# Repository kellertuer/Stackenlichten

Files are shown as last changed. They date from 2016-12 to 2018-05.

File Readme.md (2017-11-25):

# Stackenlichten
<div align="right">by <a href="https://twitter.com/kellertuer">@kellertuer</a>, <a href="https://twitter.com/k4sp4r">@k4spar</a>.</div>
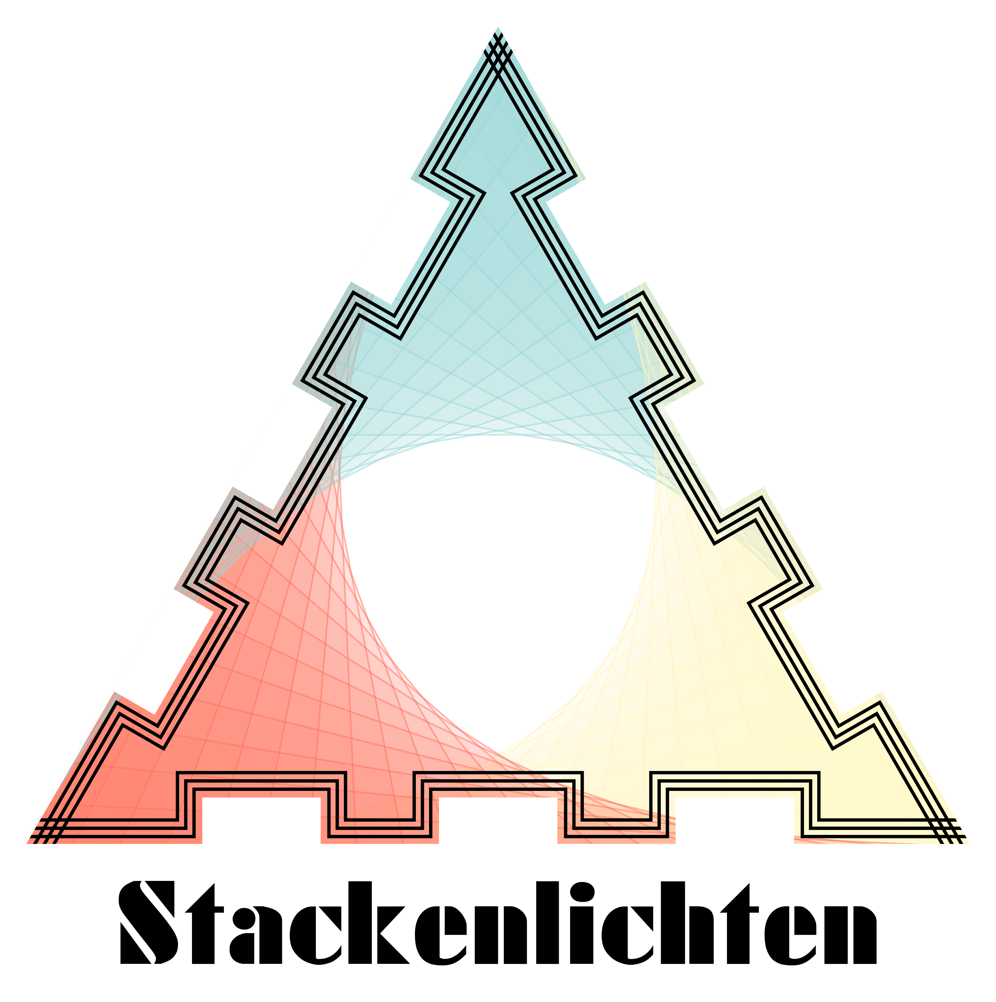
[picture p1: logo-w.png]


## Motivation
The idea of this project is to provide a blueprint for single pixels, that
can be connected via magnets. The data and power supply works via connectors.
The pixels themselves are equilateral triangles, that can easier be used to
stack different forms of Lichten.

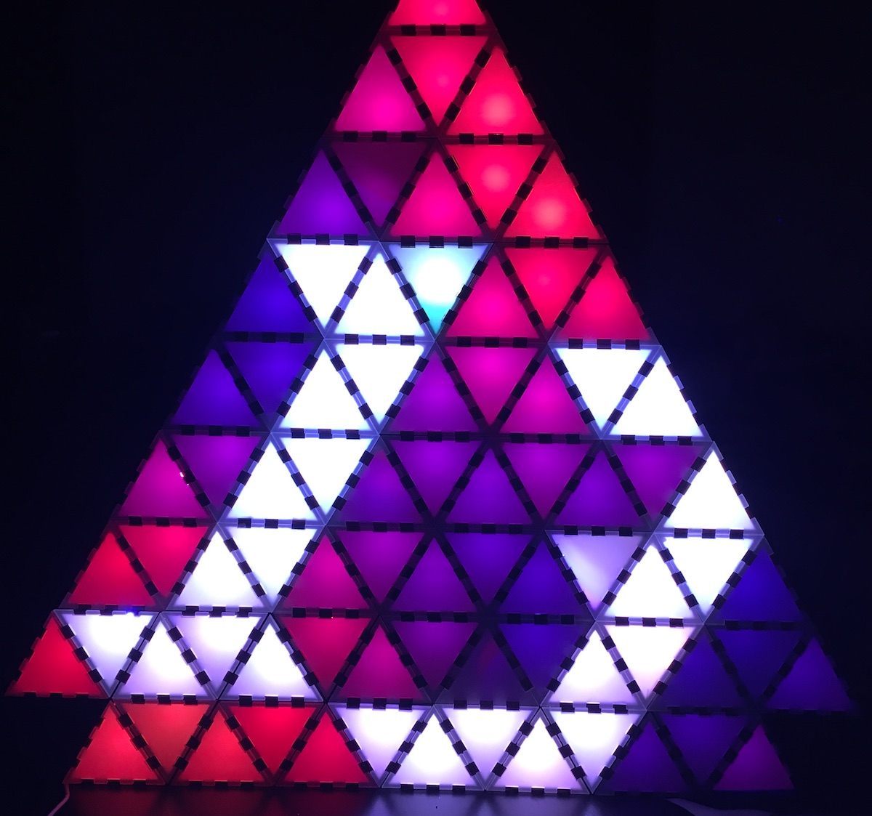
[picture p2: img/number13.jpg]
status


## Code
Based on the fadecandy chip and its accompanying python code, The code for Stackenlichten encapsulates the interface to the pixel and provides an easy way to implement image and pixel algorithms on graphs.

## A Talk with a Demo
There was a Talk at the [MetaNook 2017](https://metanook.de) by [@kellertuer](https://twitter.com/kellertuer) (in german though). The slides can be viewed [here](http://ronnybergmann.net/vortraege/2017-11-Stackenlichten-MetaNook.pdf) and a recording is available on the [Youtube channel of the MetaNook](https://www.youtube.com/watch?v=ggBUx7R-tWU) (demo starts at about 44 minutes).

## Build your own
In order to build your own Trixels, see [Manual.md](manual/manual.md).

## KuDos
* [Blinkenlichten](http://blinkenlights.net)
* [Stackenblochen](https://www.youtube.com/watch?v=QEN5-_93gQg)
* [inKL](http://chaos-inkl.de) for all 3D printing help
* [@k4spar](http://twitter.com/k4spar) for a lot of laz0r wood and discussions in the begginnig of the trixel idea at the [33c3](https://events.ccc.de/congress/2016/wiki/Main_Page).
* Haruto end eBrnd as well as [FabLab KA](https://fablab-karlsruhe.de) for even more laz0r

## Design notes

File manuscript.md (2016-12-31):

# Stackenlichten
<div align="right"> by [@kellertuer](https://twitter,com/kellertuer), [@k4sp4r](https://twitter.com/k4sp4r)</div>
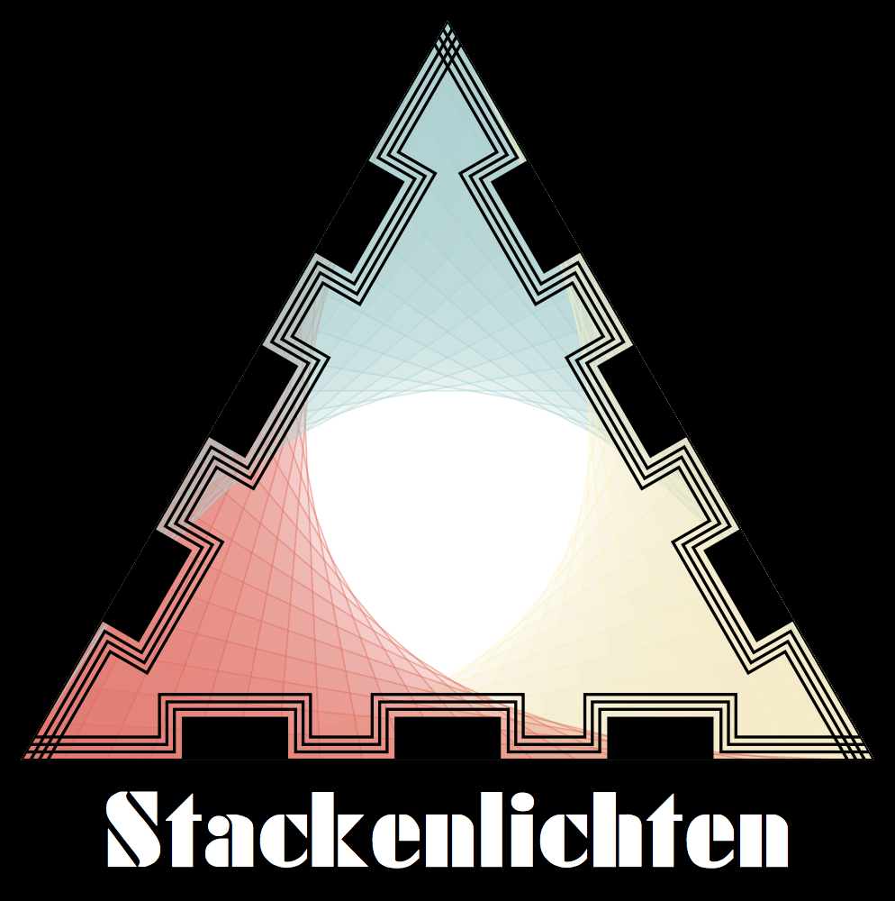
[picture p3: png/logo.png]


## Motivation
The idea of this project is to provide a blueprint for single pixels, that
can be connected via magnets. The data and power supply works via connectors.
The pixels themselves are equilateral triangles, that can easire be used to
stack different forms of Lichten.

## Material
For bulding one of the pixels the following is required
* 6 [Neodyn magnets](https://www.magnetversand.de/en/neodymium-magnet-cube-4x4x4-mm/a-173/) of size `4x4x4 mm` (0,16 €)
* 1 [connector](https://www.reichelt.de/Molex-Vielfachsteckverbinder/MOLEX-22035035/3/index.html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) (0,14 €)
* 1 [jack](https://www.reichelt.de/Molex-Vielfachsteckverbinder/MOLEX-50375033/3/index.html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) (0,10 €)
* 1 [NeoPixel](https://www.adafruit.com/products/1559) (1,75 €) or any other WS2812 LED having the classical 4 ports +,-,in,out
* 4mm thick wood
* a laser cutter

## Sketches
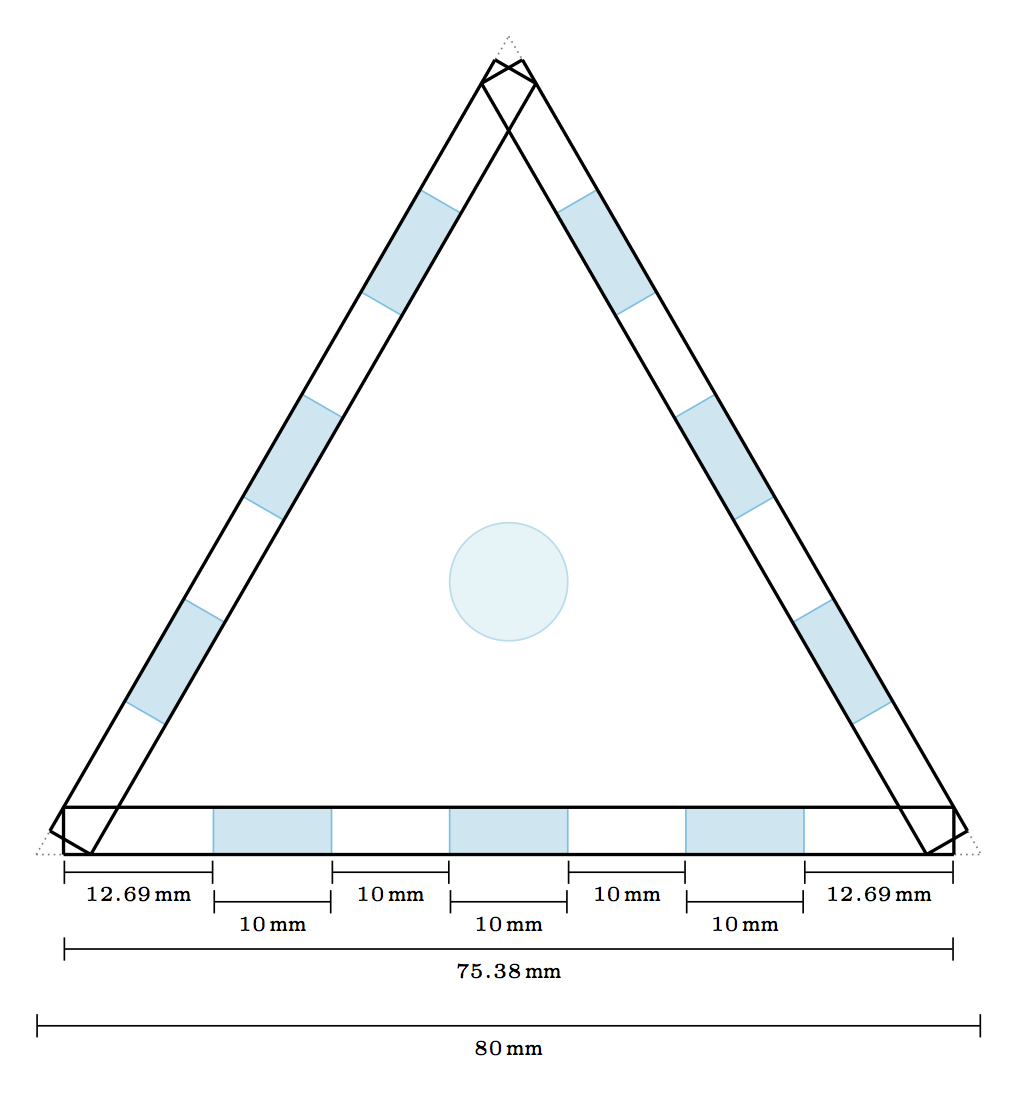
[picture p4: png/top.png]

Seen from the top, the pixel consists of 3 equal sides. with finger joints of
1cm indicated in cyan (the fingers). The three sides are shortened, such that
the edges don't overlap the triangular shape.
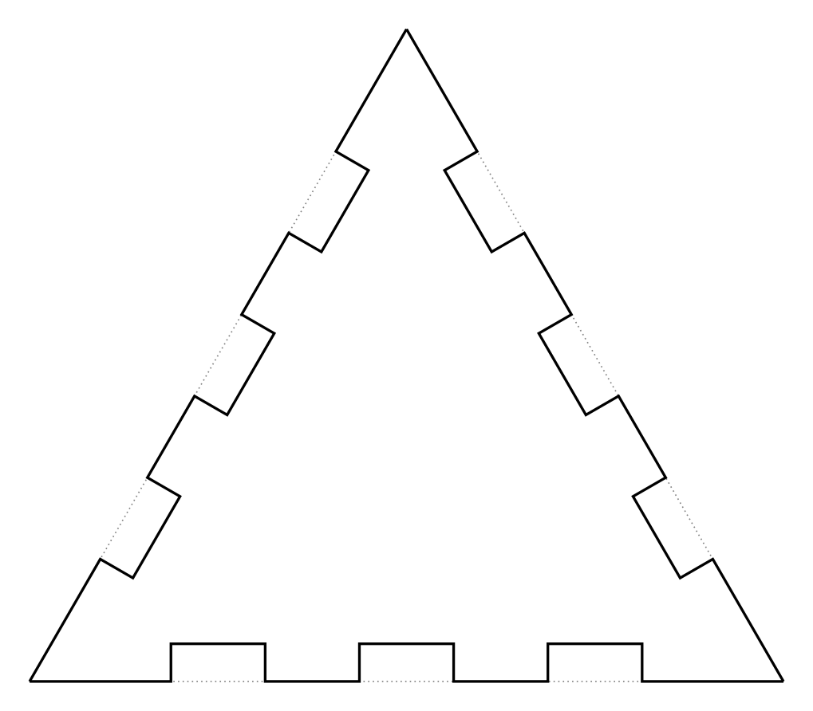
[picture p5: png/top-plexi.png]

The top plate made of plexi glas obtains a shape, that looks quite fance but is
basically just the triangular shape with the fingers of `0.4x1 cm` cut out.
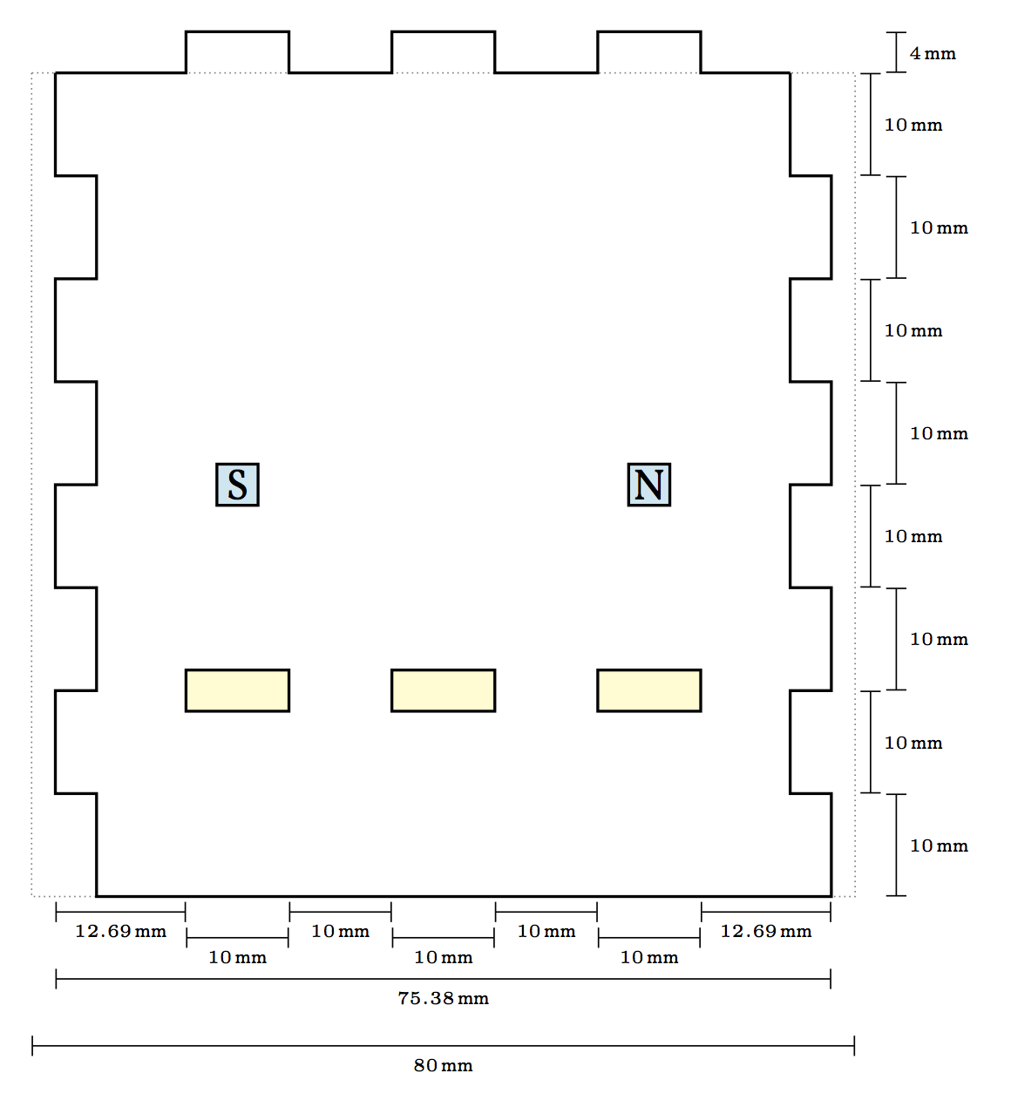
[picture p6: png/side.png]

Each side plate is made with equal fingers for the sides, but for each pixel
two sides sould consists of the same pole pointing outward ([S]outh in the sketch)
and one having the other. This yields South dominated or North dominated pixels,
which should be produced in equal amounts.
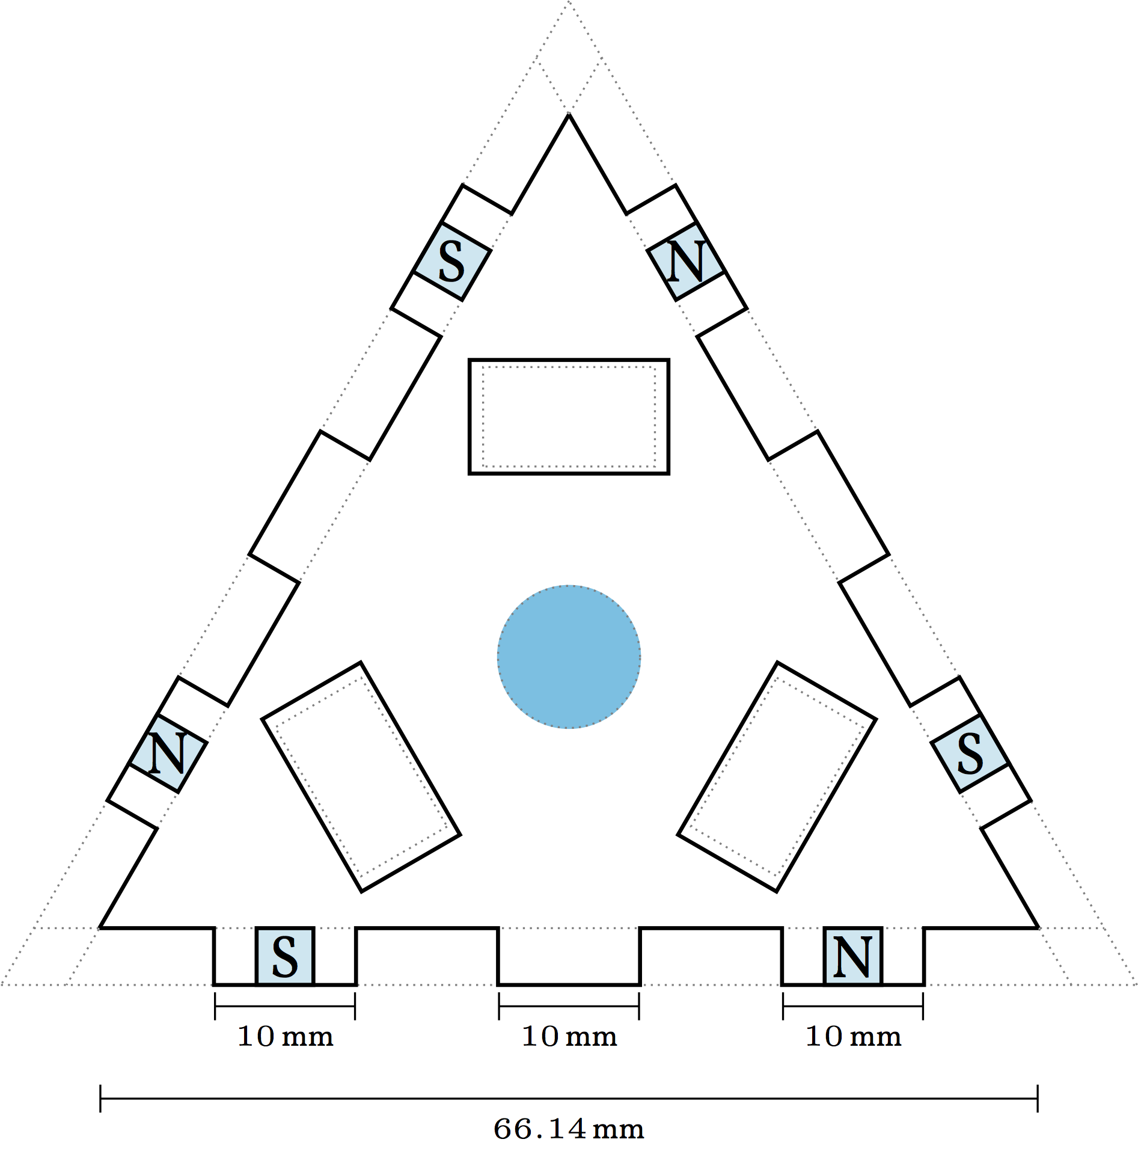
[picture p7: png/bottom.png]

The bottom plate is placed 1cm inwards of the sides with 2 bolts for each side.
The magnets should join into the sides by 3/4th (`3 mm`) the top one should be
glued, the bottom one should be held by the bottom plate.

## KuDos
* [Blinkenlichten](http://blinkenlights.net)
* [Stackenblochen](https://www.youtube.com/watch?v=QEN5-_93gQg)

## TODO
The sketches have to be transformed into laser cutting plans and a layout of
the jacks has to be made for a usual bottom plate (placement of the connector,
  length of the cable to the jack (10cm?).

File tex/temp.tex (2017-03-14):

\documentclass[border=0mm]{standalone}
\usepackage[no-math]{fontspec}
\usepackage{xunicode,xltxtra}
\usepackage{tikz,pgfplots}
\usetikzlibrary{calc,backgrounds,pgfplots.colormaps}
% Font
\defaultfontfeatures{Mapping=tex-text}
\setromanfont[Ligatures={Common},ItalicFont={Vollkorn-Italic},BoldFont={Vollkorn-Bold}, BoldItalicFont={Vollkorn-BoldItalic}]{Vollkorn}
%
% Styles
\tikzset{base/.style={gray,densely dotted,thin}}
\tikzset{main/.style={thick}}
\tikzset{minor/.style={dashed}}
\tikzset{holes/.style={thick,fill=yellow!20}}
\tikzset{magnets/.style={thick,fill=cyan!20}}
\tikzset{measure/.style={thin,|-|}}
\tikzset{emph/.style={fill=cyan!10!white,cyan!60!white}}
\tikzset{neo/.style={fill=cyan!20!white,cyan!60!white}}
\tikzset{every node/.style={font=\tiny}}
%
% Display lengths
\newif\ifshowLengths
\showLengthstrue
%\showLengthsfalse
%
%
% Sizes
%
% if unsure leave them as they're because that's the production standard for now
\newcommand\wTh{0.4} %woodThickness in cm, short W in comments
\newcommand\mTh{0.4} %MagnetThickness in cm, short M in comments
\newcommand\pTh{0.2} %plexi frontplare Thickness
\newcommand\sL{8.0} %length of a side of the Triangle
\newcommand\h{8.0} % height of the side
\begin{document}
    \begin{tikzpicture}
    \ifshowLengths
      \draw[base] (-\sL/2,0) -- (\sL/2,0);
      \draw[base] ({- (\sL/2- \wTh*cot(60)) },\wTh)--({\sL/2- \wTh*cot(60)},\wTh);
    \fi
    \draw [magnets] (-\sL/4-\mTh/2,\mTh) rectangle (-\sL/4+\mTh/2,0);
    \draw [magnets] (\sL/4-\mTh/2,\mTh) rectangle (\sL/4+\mTh/2,0);
    \ifshowLengths
      \node (A2) at (-\sL/4,\mTh/2) {\large S};
      \node (A1) at (\sL/4,\mTh/2) {\large N};
    \fi
    \draw[main] ({- (\sL/2-\wTh*cot(60) - \wTh/sin(60) )}, \wTh)
      -- (-5/16*\sL,\wTh) -- (-5/16*\sL,0) -- (-3/16*\sL,0) -- (-3/16*\sL,\wTh)
      -- (-1/16*\sL,\wTh) -- (-1/16*\sL,0) -- (1/16*\sL,0) -- (1/16*\sL,\wTh)
      -- (3/16*\sL,\wTh) -- (3/16*\sL,0) -- (5/16*\sL,0) -- (5/16*\sL,\wTh) 
      -- ({\sL/2- \wTh*cot(60) - \wTh/sin(60)},\wTh);
    % hole for plugs
    \draw[main,rounded corners=3mm]
      (-.75,{4/3*sqrt(3)+.8-.6}) rectangle (.75,{4/3*sqrt(3)+.8+.6});
    \draw[main, rounded corners=3mm]
      (-.75,{4/3*sqrt(3)-.75-.5}) rectangle (.75,{4/3*sqrt(3)-.75+.5});
    \begin{scope}[shift={(-\sL/4,{2*sqrt(3)})},rotate=-120]
    \ifshowLengths
      \draw[base] (-\sL/2,0) -- (\sL/2,0);
      \draw[base] ({- (\sL/2- \wTh*cot(60)) },\wTh)--({\sL/2- \wTh*cot(60)},\wTh);
    \fi
    \draw [magnets] (-\sL/4-\mTh/2,\mTh) rectangle (-\sL/4+\mTh/2,0);
    \draw [magnets] (\sL/4-\mTh/2,\mTh) rectangle (\sL/4+\mTh/2,0);
    \ifshowLengths
      \node (A2) at (-\sL/4,\mTh/2) {\large S};
      \node (A1) at (\sL/4,\mTh/2) {\large N};
    \fi
    \draw[main] ({- (\sL/2-\wTh*cot(60) - \wTh/sin(60) )}, \wTh)
      -- (-5/16*\sL,\wTh) -- (-5/16*\sL,0) -- (-3/16*\sL,0) -- (-3/16*\sL,\wTh)
      -- (-1/16*\sL,\wTh) -- (-1/16*\sL,0) -- (1/16*\sL,0) -- (1/16*\sL,\wTh)
      -- (3/16*\sL,\wTh) -- (3/16*\sL,0) -- (5/16*\sL,0) -- (5/16*\sL,\wTh) 
      -- ({\sL/2- \wTh*cot(60) - \wTh/sin(60)},\wTh);
    \end{scope}
    \begin{scope}[shift={(\sL/4,{2*sqrt(3)})},rotate=120]
    \ifshowLengths
      \draw[base] (-\sL/2,0) -- (\sL/2,0);
      \draw[base] ({- (\sL/2- \wTh*cot(60)) },\wTh)--({\sL/2- \wTh*cot(60)},\wTh);
    \fi
    \draw [magnets] (-\sL/4-\mTh/2,\mTh) rectangle (-\sL/4+\mTh/2,0);
    \draw [magnets] (\sL/4-\mTh/2,\mTh) rectangle (\sL/4+\mTh/2,0);
    \ifshowLengths
      \node (A2) at (-\sL/4,\mTh/2) {\large S};
      \node (A1) at (\sL/4,\mTh/2) {\large N};
    \fi
    \draw[main] ({- (\sL/2-\wTh*cot(60) - \wTh/sin(60) )}, \wTh)
      -- (-5/16*\sL,\wTh) -- (-5/16*\sL,0) -- (-3/16*\sL,0) -- (-3/16*\sL,\wTh)
      -- (-1/16*\sL,\wTh) -- (-1/16*\sL,0) -- (1/16*\sL,0) -- (1/16*\sL,\wTh)
      -- (3/16*\sL,\wTh) -- (3/16*\sL,0) -- (5/16*\sL,0) -- (5/16*\sL,\wTh) 
      -- ({\sL/2- \wTh*cot(60) - \wTh/sin(60)},\wTh);
    \end{scope}
    \ifshowLengths
    % Neopixel in Scale
    \draw[neo] (0,{4/3*sqrt(3)}) circle (.5cm);
    \draw[base] (0,{4/3*sqrt(3)}) circle (.5cm);
    % Masures
      \draw[measure] (-5/16*\sL,-.15) -- (-3/16*\sL,-.15)
        node[midway, below] {\pgfmathparse{10/8*\sL}%
        \pgfmathprintnumber{\pgfmathresult}\,mm};
      \draw[measure] (-1/16*\sL,-.15) -- (1/16*\sL,-.15)
        node[midway, below] {\pgfmathparse{10/8*\sL}%
        \pgfmathprintnumber{\pgfmathresult}\,mm};
      \draw[measure] (3/16*\sL,-.15) -- (5/16*\sL,-.15)
        node[midway, below] {\pgfmathparse{10/8*\sL}%
        \pgfmathprintnumber{\pgfmathresult}\,mm};
      \draw[measure] ({-(\sL/2-\wTh*cot(60)-\wTh/sin(60) )},-.8)
        -- ({4- \wTh*cot(60)-\wTh/sin(60)},-.8)
        node[midway,below]
        {\pgfmathparse{10*(8-2*\wTh*cot(60) - 2*\wTh/sin(60) )}%
        \pgfmathprintnumber{\pgfmathresult}\,mm};
    \fi
    \end{tikzpicture}
\end{document}

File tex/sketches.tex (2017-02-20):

% !TEX TS-program = xelatex
% !TEX TS-options = --shell-escape

%
% A unified file to generate the sketches (PDF/Vectorgraphics) of the
%   Stackenblocken Pixel construction
%
% @kellertuer, 2017-01-01
\documentclass[a4paper]{scrartcl}
\usepackage[no-math]{fontspec}
\usepackage{xunicode,xltxtra}
\usepackage{tikz}
\usepackage{unicode-math}
\usetikzlibrary{calc,external}
\tikzexternalize
\tikzset{
    external/system call={%
    xelatex \tikzexternalcheckshellescape
    -halt-on-error -interaction=batchmode --shell-escape
    -jobname "\image" "\texsource"}}
% Font
\defaultfontfeatures{Mapping=tex-text}
\setromanfont[Ligatures={Common},ItalicFont={Vollkorn-Italic},BoldFont={Vollkorn-Bold}, BoldItalicFont={Vollkorn-BoldItalic}]{Vollkorn}
%
% Styles
\tikzset{base/.style={gray,densely dotted,thin}}
\tikzset{main/.style={thick}}
\tikzset{minor/.style={dashed}}
\tikzset{holes/.style={thick,fill=yellow!20}}
\tikzset{magnets/.style={thick,fill=cyan!20}}
\tikzset{measure/.style={thin,|-|}}
\tikzset{emph/.style={fill=cyan!10!white,cyan!60!white}}
\tikzset{neo/.style={fill=cyan!20!white,cyan!60!white}}
\tikzset{every node/.style={font=\tiny}}
%
% Display lengths
\newif\ifshowLengths
\showLengthstrue
%\showLengthsfalse
\ifshowLengths
  \tikzexternalize[prefix=sketch-full-]
\else
  \tikzexternalize[prefix=sketch-]
\fi
%
%
% Sizes
%
% if unsure leave them as they're because that's the production standard for now
\newcommand\wTh{0.4} %woodThickness in cm, short W in comments
\newcommand\mTh{0.4} %MagnetThickness in cm, short M in comments
\newcommand\pTh{0.2} %plexi frontplare Thickness
\newcommand\sL{8.0} %length of a side of the Triangle
\newcommand\h{8.0} % height of the side
\begin{document}
  \begin{figure}\centering
    \tikzsetnextfilename{top}
    \begin{tikzpicture}
      %emhasized elements on the top sides of the wood side elements
      \ifshowLengths
        \draw[emph] (-\sL/16,0) rectangle (\sL/16,\wTh);
        \draw[emph] (-5*\sL/16,0) rectangle (-3*\sL/16,\wTh);
        \draw[emph] (5*\sL/16,0) rectangle (3*\sL/16,\wTh);
      % a base line
      \draw[base] (-\sL/2,0) -- (\sL/2,0);
      \fi
      % wood boundary
      \draw[main] ({- ( \sL/2 -  \wTh*cot(60) )}, \wTh) -- ({\sL/2 -  \wTh*cot(60)},\wTh);
      \draw[main] ({- ( \sL/2 -  \wTh*cot(60) )}, 0) -- ({\sL/2 -  \wTh*cot(60)},0);
      \draw[main] ({- ( \sL/2 -  \wTh*cot(60) )}, \wTh) -- ++(0,-\wTh);
      \draw[main] ({\sL/2 -  \wTh*cot(60)}, \wTh) -- ++(0,-\wTh);
      % Left side
      \begin{scope}[shift={(-\sL/4,{1/2*sqrt((1-1/4)*\sL*\sL)})},rotate=60]
      \ifshowLengths
        \draw[base] (-\sL/2,0) -- (\sL/2,0);
        \draw[emph] (-\sL/16,0) rectangle (\sL/16,-\wTh);
        \draw[emph] (-5*\sL/16,0) rectangle (-3*\sL/16,-\wTh);
        \draw[emph] (5*\sL/16,0) rectangle (3*\sL/16,-\wTh);
      \fi
       \draw[main] ({- ( \sL/2 -  \wTh*cot(60) )},-\wTh) -- ({\sL/2 -  \wTh*cot(60)},-\wTh);
        \draw[main] ({- ( \sL/2 -  \wTh*cot(60) )}, 0) -- ({\sL/2 -  \wTh*cot(60)},0);
        \draw[main] ({- ( \sL/2 -  \wTh*cot(60) )},-\wTh) -- ++(0,\wTh);
        \draw[main] ({\sL/2 -  \wTh*cot(60)},-\wTh) -- ++(0,\wTh);
      \end{scope}
      %right side
      \begin{scope}[shift={(\sL/4,{1/2*sqrt((1-1/4)*\sL*\sL)})},rotate=-60]
        \ifshowLengths
          \draw[base] (-\sL/2,0) -- (\sL/2,0);
          \draw[emph] (-\sL/16,0) rectangle (\sL/16,-\wTh);
          \draw[emph] (-5*\sL/16,0) rectangle (-3*\sL/16,-\wTh);
          \draw[emph] (5*\sL/16,0) rectangle (3*\sL/16,-\wTh);
       \fi
       \draw[main] ({- ( \sL/2 -  \wTh*cot(60) )},-\wTh) -- ({\sL/2 -  \wTh*cot(60)},-\wTh);
        \draw[main] ({- ( \sL/2 -  \wTh*cot(60) )}, 0) -- ({\sL/2 -  \wTh*cot(60)},0);
        \draw[main] ({- ( \sL/2 -  \wTh*cot(60) )},-\wTh) -- ++(0,\wTh);
        \draw[main] ({\sL/2 -  \wTh*cot(60)},-\wTh) -- ++(0,\wTh);
      \end{scope}
      % Neopixel in Scale
      \ifshowLengths
        \draw[neo] (0,{1/3*sqrt((1-1/4)*\sL*\sL)}) circle (.5cm);
      % Measures
        \draw[measure] ({- ( \sL/2 -  \wTh*cot(60) )},-.15) -- (-5*\sL/16,-.15)
          node[midway,below] {\pgfmathparse{10*(3*\sL/16 - \wTh*cot(60))}%
          \pgfmathprintnumber{\pgfmathresult}\,mm};
         \draw[measure] (-5*\sL/16,-.15-.25) -- (-3*\sL/16,-.15-.25) node[midway, below]{\pgfmathparse{10*\sL/8}%
                \pgfmathprintnumber{\pgfmathresult}\,mm};
         \draw[measure] (-3*\sL/16,-.15) -- (-\sL/16,-.15) node[midway, below]{\pgfmathparse{10*\sL/8}%
                \pgfmathprintnumber{\pgfmathresult}\,mm};
         \draw[measure] (-\sL/16,-.15-.25) -- (\sL/16,-.15-.25) node[midway, below]{\pgfmathparse{10*\sL/8}%
                \pgfmathprintnumber{\pgfmathresult}\,mm};
         \draw[measure] (\sL/16,-.15) -- (3*\sL/16,-.15) node[midway, below]{\pgfmathparse{10*\sL/8}%
                \pgfmathprintnumber{\pgfmathresult}\,mm};
         \draw[measure] (3*\sL/16,-.15-.25) -- (5*\sL/16,-.15-.25) node[midway, below]{\pgfmathparse{10*\sL/8}%
                \pgfmathprintnumber{\pgfmathresult}\,mm};
        \draw[measure] ({( \sL/2 -  \wTh*cot(60) )},-.15) -- (5*\sL/16,-.15)
          node[midway,below] {\pgfmathparse{10*(3*\sL/16 - \wTh*cot(60))}%
          \pgfmathprintnumber{\pgfmathresult}\,mm};
      \draw[measure] ({- ( \sL/2 -  \wTh*cot(60) )},-.8) -- ({\sL/2 -  \wTh*cot(60)},-.8)
         node[midway,below] {\pgfmathparse{10*(\sL - 2*\wTh*cot(60))}%
         \pgfmathprintnumber{\pgfmathresult}\,mm};
      \draw[measure] (-\sL/2,-1.45) -- (\sL/2,-1.45) node [midway, below]{\pgfmathparse{10*\sL}%
                \pgfmathprintnumber{\pgfmathresult}\,mm};
      \draw[measure] (\sL/2+.4,0) -- (\sL/2+.4,{1/3*sqrt((1-1/4)*\sL*\sL)})
        node[midway, right] {\pgfmathparse{10/3*sqrt((1-1/4)*\sL*\sL)}
                \pgfmathprintnumber{\pgfmathresult}\,mm};
      \draw[measure] (\sL/2+.15,0) -- (\sL/2+.15,{sqrt((1-1/4)*\sL*\sL)})
        node[midway, left] {\pgfmathparse{10*sqrt((1-1/4)*\sL*\sL)}
                \pgfmathprintnumber{\pgfmathresult}\,mm};
      \fi
    \end{tikzpicture}
    \caption{Top view with side plates}
  \end{figure}
  \begin{figure}\centering
    \tikzsetnextfilename{plexi}
    \begin{tikzpicture}
        \ifshowLengths\draw[base] (-\sL/2,0) -- (\sL/2,0);\fi
        \draw[main] (-\sL/2,0) -- (-5*\sL/16,0) -- (-5*\sL/16,\wTh)
         -- (-3*\sL/16,\wTh) -- (-1.5,0) -- (-\sL/16,0) -- (-\sL/16,\wTh)
         -- (\sL/16,\wTh) -- (\sL/16,0) -- (3*\sL/16,0) -- (3*\sL/16,\wTh)
         -- (5*\sL/16,\wTh) -- (5*\sL/16,0) -- (\sL/2,0);
      \begin{scope}[shift={(-\sL/4,{2*sqrt(3)})},rotate=60] % shift left and halft trig height
        \ifshowLengths\draw[base] (-\sL/2,0) -- (\sL/2,0);\fi
        \draw[main] (-\sL/2,0) -- (-5*\sL/16,0) -- (-5*\sL/16,-\wTh)
         -- (-3*\sL/16,-\wTh) -- (-1.5,0) -- (-\sL/16,0) -- (-\sL/16,-\wTh)
         -- (\sL/16,-\wTh) -- (\sL/16,0) -- (3*\sL/16,0) -- (3*\sL/16,-\wTh)
         -- (5*\sL/16,-\wTh) -- (5*\sL/16,0) -- (\sL/2,0);
      \end{scope}
      \begin{scope}[shift={(\sL/4,{2*sqrt(3)})},rotate=-60]
        \ifshowLengths\draw[base] (-\sL/2,0) -- (\sL/2,0);\fi
        \draw[main] (-\sL/2,0) -- (-5*\sL/16,0) -- (-5*\sL/16,-\wTh)
         -- (-3*\sL/16,-\wTh) -- (-1.5,0) -- (-\sL/16,0) -- (-\sL/16,-\wTh)
         -- (\sL/16,-\wTh) -- (\sL/16,0) -- (3*\sL/16,0) -- (3*\sL/16,-\wTh)
         -- (5*\sL/16,-\wTh) -- (5*\sL/16,0) -- (\sL/2,0);
      \end{scope}
    \end{tikzpicture}
    \caption{Top (plexi glass) plate form}
  \end{figure}
  \begin{figure}\centering
    \tikzsetnextfilename{side}
    \begin{tikzpicture}
      \ifshowLengths\draw[base] (-\sL/2,\h) rectangle (\sL/2,0);\fi
      \draw[main] ({-(\sL/2-\wTh*cot(60)-\wTh)},\h) -- (-5*\sL/16,\h)
        -- (-5*\sL/16,\h+\pTh) -- (-3*\sL/16,8+\pTh)
        -- (-3*\sL/16,\h) -- (-\sL/16,\h) -- (-\sL/16,\h+\pTh)
        -- (\sL/16,\h+\pTh) -- (\sL/16,\h) -- (3*\sL/16,\h)
        -- (3*\sL/16,\h+\pTh) -- (5*\sL/16,\h+\pTh) -- (5*\sL/16,\h)
        -- ({\sL/2- \wTh*cot(60)-2*\wTh},\h);
        %start top left - main frame
        \draw[main] ({-(\sL/2-\wTh*cot(60)-\wTh)},\h)
        -- ({-(\sL/2-\wTh*cot(60)-\wTh)},7/8*\h)
      -- ({-(\sL/2-\wTh*cot(60)-\wTh)+\wTh},7/8*\h)
        -- ({-(\sL/2-\wTh*cot(60)-\wTh)+\wTh},3/4*\h)
      -- ({-(\sL/2-\wTh*cot(60)-\wTh)},3/4*\h)
        -- ({-(\sL/2-\wTh*cot(60)-\wTh)},5/8*\h)
      -- ({-(\sL/2-\wTh*cot(60)-\wTh)+\wTh},5/8*\h)
        -- ({-(\sL/2-\wTh*cot(60)-\wTh)+\wTh},1/2*\h)
      -- ({-(\sL/2-\wTh*cot(60)-\wTh)},1/2*\h)
        -- ({-(\sL/2-\wTh*cot(60)-\wTh)},3/8*\h)
      -- ({-(\sL/2-\wTh*cot(60)-\wTh)+\wTh},3/8*\h)
        -- ({-(\sL/2-\wTh*cot(60)-\wTh)+\wTh},1/4*\h)
      -- ({-(\sL/2-\wTh*cot(60)-\wTh)},1/4*\h)
        -- ({-(\sL/2-\wTh*cot(60)-\wTh)},1/8*\h)
      -- ({-(\sL/2-\wTh*cot(60)-\wTh)+\wTh},1/8*\h)
        -- ({-(\sL/2-\wTh*cot(60)-\wTh)+\wTh},0) --%
      % bottom line
      ({(\sL/2-\wTh*cot(60)-\wTh)},0)
      % and upwards
      -- ({(\sL/2-\wTh*cot(60)-\wTh)},1/8*\h) -- ({(\sL/2-\wTh*cot(60)-\wTh)-\wTh},1/8*\h)
      -- ({(\sL/2-\wTh*cot(60)-\wTh)-\wTh},1/4*\h) -- ({(\sL/2-\wTh*cot(60)-\wTh)},1/4*\h)
      -- ({(\sL/2-\wTh*cot(60)-\wTh)},3/8*\h) -- ({(\sL/2-\wTh*cot(60)-\wTh)-\wTh},3/8*\h)
      -- ({(\sL/2-\wTh*cot(60)-\wTh)-\wTh},1/2*\h) -- ({(\sL/2-\wTh*cot(60)-\wTh)},1/2*\h)
      -- ({(\sL/2-\wTh*cot(60)-\wTh)},5/8*\h) -- ({(\sL/2-\wTh*cot(60)-\wTh)-\wTh},5/8*\h)
      -- ({(\sL/2-\wTh*cot(60)-\wTh)-\wTh},3/4*\h) -- ({(\sL/2-\wTh*cot(60)-\wTh)},3/4*\h)
      -- ({(\sL/2-\wTh*cot(60)-\wTh)},7/8*\h) -- ({(\sL/2-\wTh*cot(60)-\wTh)-\wTh},7/8*\h)
      -- ({(\sL/2-\wTh*cot(60)-\wTh)-\wTh},\h);
      % % bottom plate
    \draw [magnets] (-\sL/4-\mTh/2,\h/2-\mTh/2)
      rectangle (-\sL/4+\mTh/2,\h/2+\mTh/2);
    \draw [magnets] (\sL/4-\mTh/2,\h/2-\mTh/2)
      rectangle (\sL/4+\mTh/2,\h/2+\mTh/2);
    \ifshowLengths
      \node (A) at (\sL/4,\h/2) {\large N};
      \node (A) at (-\sL/4,\h/2) {\large S};
    \fi
    % bottom plate holes
    \draw [holes] (-5/16*\sL,\h/4-\wTh/2) rectangle (-3/16*\h,\h/4+\wTh/2);
    \draw [holes] (-1/16*\sL,\h/4-\wTh/2) rectangle (1/16*\h,\h/4+\wTh/2);
    \draw [holes] (3/16*\sL,\h/4-\wTh/2) rectangle (5/16*\h,\h/4+\wTh/2);
    %
    % Measures
    %
    \ifshowLengths
    % bottom    
    \draw[measure] ({-(\sL/2- \wTh*cot(60) - \wTh)},-.15) -- (-5/16*\sL,-.15)
      node[midway,below] {\pgfmathparse{10*(3/16*\sL - \wTh*cot(60)-\wTh)}%
        \pgfmathprintnumber{\pgfmathresult}\,mm};
    \draw[measure] (-5/16*\sL,-.15-.25) -- (-3/16*\sL,-.15-.25)
      node[midway, below] {\pgfmathparse{10/8*\sL}%
        \pgfmathprintnumber{\pgfmathresult}\,mm};
    \draw[measure] (-3/16*\sL,-.15) -- (-1/16*\sL,-.15)
        node [midway, below] {\pgfmathparse{10/8*\sL}%
        \pgfmathprintnumber{\pgfmathresult}\,mm};
    \draw[measure] (-1/16*\sL,-.15-.25) -- (1/16*\sL,-.15-.25)
        node [midway, below] {\pgfmathparse{10/8*\sL}%
        \pgfmathprintnumber{\pgfmathresult}\,mm};
    \draw[measure] (1/16*\sL,-.15) -- (3/16*\sL,-.15)
        node [midway, below] {\pgfmathparse{10/8*\sL}%
        \pgfmathprintnumber{\pgfmathresult}\,mm};
    \draw[measure] (3/16*\sL,-.15-.25) -- (5/16*\sL,-.15-.25)
        node [midway, below] {\pgfmathparse{10/8*\sL}%
        \pgfmathprintnumber{\pgfmathresult}\,mm};
    \draw[measure] ({(\sL/2- \wTh*cot(60) -\wTh)},-.15) -- (5/16*\sL,-.15)
        node[midway,below] {\pgfmathparse{10*(3/16*\sL - \wTh*cot(60)-\wTh)}%
        \pgfmathprintnumber{\pgfmathresult}\,mm};
    \draw[measure] ({- (\sL/2- \wTh*cot(60) - \wTh)},-.8)
        -- ({\sL/2- \wTh*cot(60)-\wTh},-.8)
        node[midway,below] {\pgfmathparse{10*(\sL - 2*\wTh*cot(60)-2*\wTh)}%
       \pgfmathprintnumber{\pgfmathresult}\,mm};
    \draw[measure] (-\sL/2,-1.45) -- (\sL/2,-1.45)
        node [midway, below] {\pgfmathparse{10*\sL}%
        \pgfmathprintnumber{\pgfmathresult}\,mm};
    % % left
    \draw[measure] (\sL/2+.15+.25,\h+\pTh) -- (\sL/2+.15+.25,\h)
    node[midway,right] {\pgfmathparse{10*\pTh}\pgfmathprintnumber{\pgfmathresult}\,mm};
    \draw[measure] (\sL/2+.15,\h) -- (\sL/2+.15,7/8*\h) node[midway,right]
      {\pgfmathparse{10/8*\h}\pgfmathprintnumber{\pgfmathresult}\,mm};
    \draw[measure] (4.15+.25,7/8*\h) -- (4.15+.25,6/8*\h) node[midway,right]
      {\pgfmathparse{10/8*\h}\pgfmathprintnumber{\pgfmathresult}\,mm};
    \draw[measure] (\sL/2+.15,6/8*\h) -- (\sL/2+.15,5/8*\h) node[midway,right]
      {\pgfmathparse{10/8*\h}\pgfmathprintnumber{\pgfmathresult}\,mm};
    \draw[measure] (4.15+.25,5/8*\h) -- (4.15+.25,4/8*\h) node[midway,right]
      {\pgfmathparse{10/8*\h}\pgfmathprintnumber{\pgfmathresult}\,mm};
    \draw[measure] (\sL/2+.15,4/8*\h) -- (\sL/2+.15,3/8*\h) node[midway,right]
      {\pgfmathparse{10/8*\h}\pgfmathprintnumber{\pgfmathresult}\,mm};
    \draw[measure] (4.15+.25,3/8*\h) -- (4.15+.25,2/8*\h) node[midway,right]
      {\pgfmathparse{10/8*\h}\pgfmathprintnumber{\pgfmathresult}\,mm};
    \draw[measure] (\sL/2+.15,2/8*\h) -- (\sL/2+.15,1/8*\h) node[midway,right]
      {\pgfmathparse{10/8*\h}\pgfmathprintnumber{\pgfmathresult}\,mm};
    \draw[measure] (4.15+.25,1/8*\h) -- (4.15+.25,0) node[midway,right]
      {\pgfmathparse{10/8*\h}\pgfmathprintnumber{\pgfmathresult}\,mm};
    \fi
    \end{tikzpicture}
    \caption{A side}
  \end{figure}
  \begin{figure}\centering
    \tikzsetnextfilename{bottom}
    \begin{tikzpicture}
    \ifshowLengths
      \draw[base] (-\sL/2,0) -- (\sL/2,0);
      \draw[base] ({- (\sL/2- \wTh*cot(60)) },\wTh)--({\sL/2- \wTh*cot(60)},\wTh);
    \fi
    \draw [magnets] (-\sL/4-\mTh/2,5*\mTh/4) rectangle (-\sL/4+\mTh/2,\mTh/4);
    \draw [magnets] (\sL/4-\mTh/2,5*\mTh/4) rectangle (\sL/4+\mTh/2,\mTh/4);
    \ifshowLengths
      \node (A2) at (-\sL/4,3*\mTh/4) {\large S};
      \node (A1) at (\sL/4,3*\mTh/4) {\large N};
    \fi
    \draw[main] ({- (\sL/2-\wTh*cot(60) - \wTh/sin(60) )}, \wTh)
      -- (-5/16*\sL,\wTh) -- (-5/16*\sL,0) -- (-3/16*\sL,0) -- (-3/16*\sL,\wTh)
      -- (-1/16*\sL,\wTh) -- (-1/16*\sL,0) -- (1/16*\sL,0) -- (1/16*\sL,\wTh)
      -- (3/16*\sL,\wTh) -- (3/16*\sL,0) -- (5/16*\sL,0) -- (5/16*\sL,\wTh) 
      -- ({\sL/2- \wTh*cot(60) - \wTh/sin(60)},\wTh);
    \begin{scope}[shift={(-\sL/4,{2*sqrt(3)})},rotate=60]
      \ifshowLengths
        \draw[base] (-\sL/2,0) -- (\sL/2,0);
        \draw[base] ({- (\sL/2-\wTh*cot(60) )},-\wTh)
          -- ({4- \wTh*cot(60)},-\wTh);
      \fi
      \draw [magnets] (-\sL/4-\mTh/2,-5*\mTh/4) rectangle (-\sL/4+\mTh/2,-\mTh/4);
      \draw [magnets] (\sL/4-\mTh/2,-5*\mTh/4) rectangle (\sL/4+\mTh/2,-\mTh/4);
      \ifshowLengths
        \node (A2) at (-\sL/4,-3*\mTh/4) {\large N};
        \node (A1) at (\sL/4,-3*\mTh/4) {\large S};
      \fi
    \draw[main] ({- (\sL/2-\wTh*cot(60) - \wTh/sin(60) )}, -\wTh)
    -- (-5/16*\sL,-\wTh) -- (-5/16*\sL,0) -- (-3/16*\sL,0) -- (-3/16*\sL,-\wTh)
      -- (-1/16*\sL,-\wTh) -- (-1/16*\sL,0) -- (1/16*\sL,0) -- (1/16*\sL,-\wTh)
      -- (3/16*\sL,-\wTh) -- (3/16*\sL,0) -- (5/16*\sL,0) -- (5/16*\sL,-\wTh) 
      -- ({\sL/2- \wTh*cot(60) - \wTh/sin(60)},-\wTh);
    \end{scope}
    \begin{scope}[shift={(\sL/4,{2*sqrt(3)})},rotate=-60]
      \ifshowLengths
        \draw[base] (-\sL/2,0) -- (\sL/2,0);
        \draw[base] ({- (\sL/2-\wTh*cot(60) )},-\wTh)
          -- ({4- \wTh*cot(60)},-\wTh);
      \fi
    \draw [magnets] (-\sL/4-\mTh/2,-5*\mTh/4) rectangle (-\sL/4+\mTh/2,-\mTh/4);
    \draw [magnets] (\sL/4-\mTh/2,-5*\mTh/4) rectangle (\sL/4+\mTh/2,-\mTh/4);
    \ifshowLengths
      \node (A2) at (-\sL/4,-3*\mTh/4) {\large N};
      \node (A1) at (\sL/4,-3*\mTh/4) {\large S};
    \fi
    \draw[main] ({- (\sL/2-\wTh*cot(60) - \wTh/sin(60) )}, -\wTh)
    -- (-5/16*\sL,-\wTh) -- (-5/16*\sL,0) -- (-3/16*\sL,0) -- (-3/16*\sL,-\wTh)
      -- (-1/16*\sL,-\wTh) -- (-1/16*\sL,0) -- (1/16*\sL,0) -- (1/16*\sL,-\wTh)
      -- (3/16*\sL,-\wTh) -- (3/16*\sL,0) -- (5/16*\sL,0) -- (5/16*\sL,-\wTh) 
      -- ({\sL/2- \wTh*cot(60) - \wTh/sin(60)},-\wTh);
    \end{scope}
    \ifshowLengths
    % Neopixel in Scale
    \draw[neo] (0,{4/3*sqrt(3)}) circle (.5cm);
    % Masures
      \draw[measure] (-5/16*\sL,-.15) -- (-3/16*\sL,-.15)
        node[midway, below] {\pgfmathparse{10/8*\sL}%
        \pgfmathprintnumber{\pgfmathresult}\,mm};
      \draw[measure] (-1/16*\sL,-.15) -- (1/16*\sL,-.15)
        node[midway, below] {\pgfmathparse{10/8*\sL}%
        \pgfmathprintnumber{\pgfmathresult}\,mm};
      \draw[measure] (3/16*\sL,-.15) -- (5/16*\sL,-.15)
        node[midway, below] {\pgfmathparse{10/8*\sL}%
        \pgfmathprintnumber{\pgfmathresult}\,mm};
      \draw[measure] ({-(\sL/2-\wTh*cot(60)-\wTh/sin(60) )},-.8)
        -- ({4- \wTh*cot(60)-\wTh/sin(60)},-.8)
        node[midway,below]
        {\pgfmathparse{10*(8-2*\wTh*cot(60) - 2*\wTh/sin(60) )}%
        \pgfmathprintnumber{\pgfmathresult}\,mm};
    \fi
    \end{tikzpicture}
    \caption{The bottom plate.}
  \end{figure}
\end{document}

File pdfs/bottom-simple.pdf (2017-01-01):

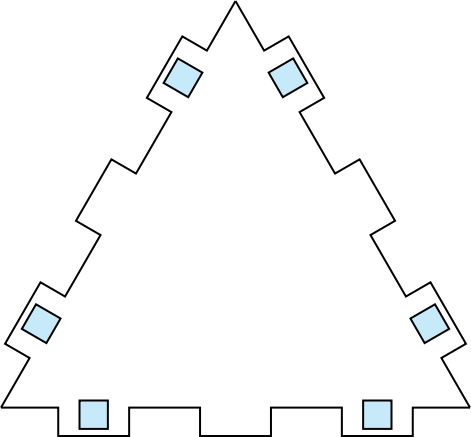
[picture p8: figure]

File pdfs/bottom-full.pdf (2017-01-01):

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

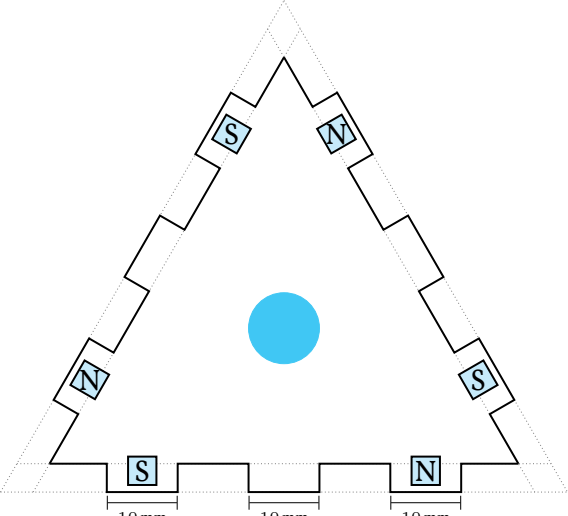
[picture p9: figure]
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

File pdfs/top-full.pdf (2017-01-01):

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

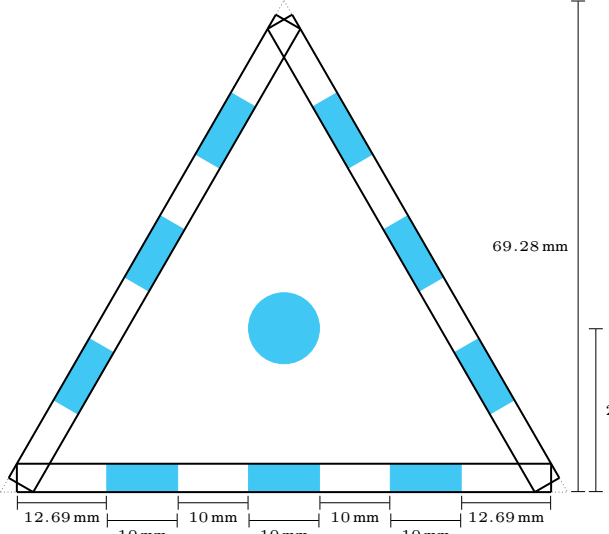
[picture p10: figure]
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

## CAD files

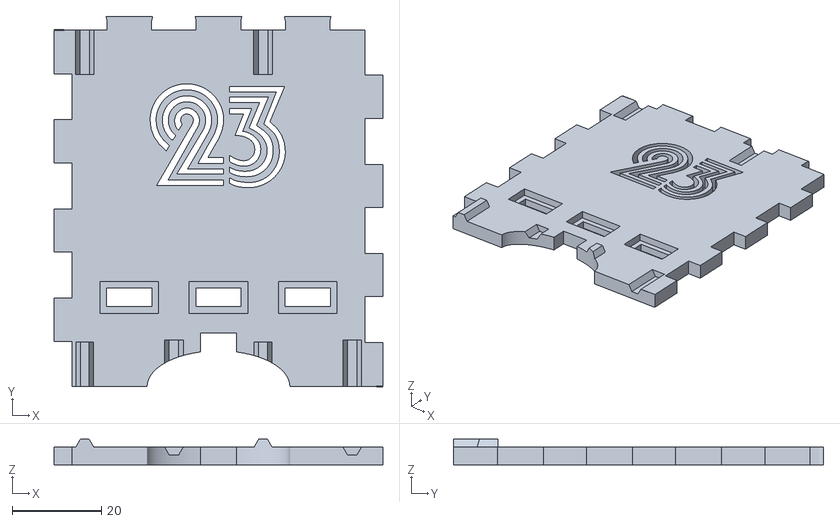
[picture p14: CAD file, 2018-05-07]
openSCAD/stl/side_num23.stl
73.7 x 83.0 x 5.73

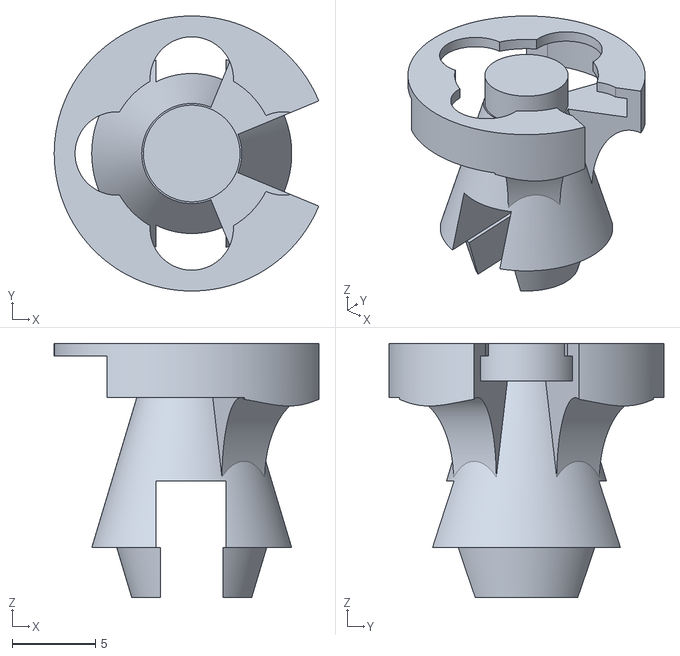
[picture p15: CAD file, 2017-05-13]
Slic3r/LED_Case.stl
15.9 x 16.5 x 15.2

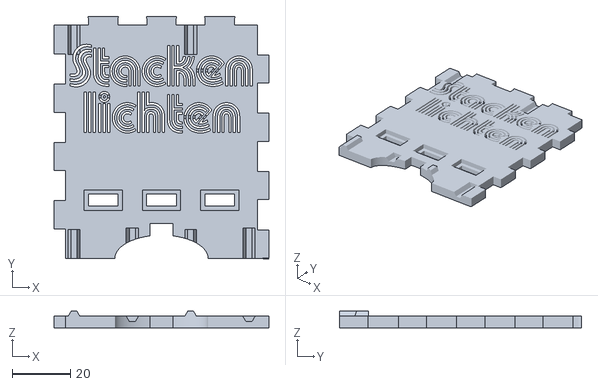
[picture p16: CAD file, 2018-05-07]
openSCAD/stl/side_stackenlichten.stl
73.7 x 83.0 x 5.73

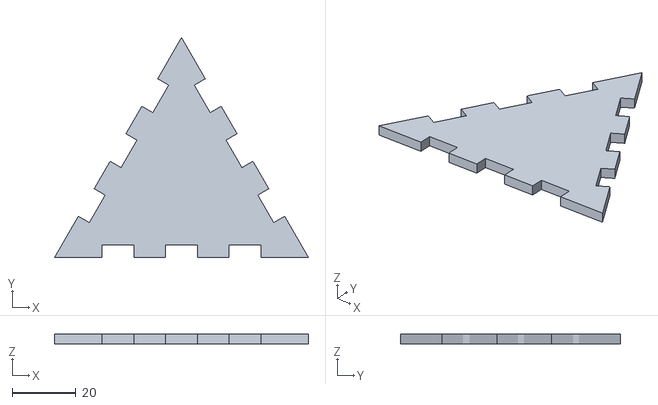
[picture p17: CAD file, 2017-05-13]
Slic3r/front.stl
80.0 x 69.3 x 3.00

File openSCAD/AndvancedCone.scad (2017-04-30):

//sAngle1 = 30;
//eAngle1 = 60;
//sAngle2 = 120;
//eAngle2 = 150;
sAngle1 = 22.5;
eAngle1 = 67.5;
sAngle2 = 112.5;
eAngle2 = 157.5;
stA1 = eAngle1-sAngle1;
stA2 = eAngle2-sAngle2;
steps = stA1;

LEDDir = 14.5;
OuterDir = 16.5;
InnerDir = 10;
height=4;
// Helper
hSp = 0.5;
//inner Helper
translate([0,0,10+hSp])
difference () {
cylinder(d1=5.8,d2=3,h=3.25-hSp,$fn=360);
cylinder(d1=4.8,d2=2,h=3.25,$fn=360);
};
//outer helpers
difference() {
    union() {
translate([0,0,10+hSp])
linear_extrude(2.5-2*hSp) polygon([for ( i = [-1:steps]) (i==-1) ? [0,0] : 
         [(LEDDir-3*hSp)/2*sin(sAngle1 + i/steps*stA1),(LEDDir-3*hSp)/2*cos(sAngle1 + i/steps*stA1)]]);
translate([0,0,10+hSp])
linear_extrude(2.5-2*hSp) polygon([for ( i = [-1:steps]) (i==-1) ? [0,0] : 
         [(LEDDir-3*hSp)/2*sin(sAngle2 + i/steps*stA2),(LEDDir-3*hSp)/2*cos(sAngle2 + i/steps*stA2)]]);
translate([0,0,12.25])
linear_extrude(1) polygon([for ( i = [-1:steps]) (i==-1) ? [0,0] : 
         [(InnerDir-3*hSp)/2*sin(sAngle1 + i/steps*stA1),(InnerDir-3*hSp)/2*cos(sAngle1 + i/steps*stA1)]]);
translate([0,0,12.25])
linear_extrude(1) polygon([for ( i = [-1:steps]) (i==-1) ? [0,0] : 
         [(InnerDir-3*hSp)/2*sin(sAngle2 + i/steps*stA2),(InnerDir-3*hSp)/2*cos(sAngle2 + i/steps*stA2)]]);
};
translate([0,0,10+hSp])
cylinder(d1=5.9+2*hSp,d2=4+2*hSp,h=3.25-hSp,$fn=360);
translate([0,0,12.75])
cube([OuterDir,OuterDir,.5*hSp],center=true);
translate([0,0,11.25])
cube([OuterDir,OuterDir,.5*hSp],center=true);
};
// Base
difference() {
    cylinder(10, 6, 3, $fn=360);
translate([-0.05,0,1.95]) cube([4.2,24,4.1],center=true);
}

translate([0,0,4])
difference() {
linear_extrude(6) polygon([for ( i = [-1:steps]) (i==-1) ? [0,0] : 
         [OuterDir/2*sin(sAngle1 + i/steps*stA1),OuterDir/2*cos(sAngle1 + i/steps*stA1)]]);
translate([5,5]) 
    rotate(v=[0,0,1], a=45) rotate(v=[1,0,0],a=90) linear_extrude(7,center=true)
        scale([.9,1.666]) circle(3,$fn=360);
}
translate([0,0,4])
difference() {
linear_extrude(6) polygon(
     [for ( i = [-1:steps]) (i==-1) ? [0,0] : 
         [OuterDir/2*sin(sAngle2 + i/steps*stA2),OuterDir/2*cos(sAngle2 + i/steps*stA2)]]);
translate([5,-5]) 
    rotate(v=[0,0,1], a=-45) rotate(v=[1,0,0],a=90) linear_extrude(7,center=true)
        scale([.9,1.666]) circle(3,$fn=360);
}
//Side Ring
translate([0,0,9]) linear_extrude(height)
difference() {
    difference() {circle(d=OuterDir,$fn=360); circle(d=LEDDir,$fn=360);};
    translate([-7,0]) square(13,center=true);
    polygon([ [0,0], [(OuterDir+6)/2*sin(eAngle1),(OuterDir+6)/2*cos(eAngle1)], [(OuterDir+6)/2*sin(sAngle2),(OuterDir+6)/2*cos(sAngle2)]]);
}
// Top Ring
translate([0,0,10-1.5+height]) linear_extrude(.75)
difference() {
    difference() {circle(d=OuterDir,$fn=360); circle(d=InnerDir,$fn=360);};
    polygon([ [0,0], [(OuterDir+6)/2*sin(eAngle1),(OuterDir+6)/2*cos(eAngle1)], [(OuterDir+6)/2*sin(sAngle2),(OuterDir+6)/2*cos(sAngle2)]]);
}
// bottom extension
difference() {
    rotate(v=[0,1,0], a=180) linear_extrude(3,scale=0.8) circle(d=9,$fn=360);
    rotate(v=[0,1,0], a=180) translate([0,0,-2]) linear_extrude(5.01,scale=1) square([3.75,10],center=true);
}

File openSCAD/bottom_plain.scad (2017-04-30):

/* 
 * Stackenlichten-Files I: The top plate
 *
 * kellertuer, 2017-02-19
 */

/*
 * Variables, all Data in mm
 */
wW = 4;    // Thickness/Width of wood
mW = 4;    //                 of a Magnet-Cube
fW = 2;    // Thickness of the front plastic plate
sL = 80;   // sidelength of a triangle
bD = 80;   // Depth of a box (depth w.r.t. frontview)
fC = 3;    // number of fingers in the triangle
fD = 4;    // number on fingers downwards
pW = 12; //width of plug inlet
pD = 8; //depth of plug inlet
pS = 40; //shift from baseline of plug inlet
// don't change these values
nC = 2*fC+2; //number of Divisions, due to 2fC+1 segments and one segment that split in the corners
sH = 2*(wW/tan(60)+wW/sin(60)); //shorten inner

// concat with shfted rotated versions... bottom left right

bottomPlate();
//color([.3,.3,.3]) translate([0,sL*sqrt(3)/6,]) circle(r=5,$fn=360,center=true);
hR = 3;

module bottomPlate() {
    linear_extrude(height=wW, twist=0)
    difference() {
    polygon(points=concat(
            genInnerSide(0,[0,0],sH,sH),
            genInnerSide(-120,[sL/4,sL*sqrt(3)/4],sH,sH),
            genInnerSide(120,[-sL/4,sL*sqrt(3)/4],sH,sH)
        ));
    translate([0,sL*sqrt(3)/6+7]) hull() {
        translate([-7.5+hR,-5+hR]) circle(r=hR,$fn=360);
        translate([-7.5+hR, 5-hR]) circle(r=hR,$fn=360);
        translate([ 7.5-hR,-5+hR]) circle(r=hR,$fn=360);
        translate([ 7.5-hR, 5-hR]) circle(r=hR,$fn=360);
       };
    translate([0,sL*sqrt(3)/6-7]) hull() {
        translate([-7.5+hR,-5+hR]) circle(r=hR,$fn=360);
        translate([-7.5+hR, 5-hR]) circle(r=hR,$fn=360);
        translate([ 7.5-hR,-5+hR]) circle(r=hR,$fn=360);
        translate([ 7.5-hR, 5-hR]) circle(r=hR,$fn=360);
    };
};
};

/*
 * Helping Functions - Generate one side of the triangle recursion olé olé
 */
function genInnerSide(a=0,v=[0,0],sLe=0,sRi=0,h=wW) = generateInnerSide([rotM(a)*[-(sL-sLe)/2,h]+v],0,a,v,sLe,sRi,h);   
//Recursively generate fC toothes
function generateInnerSide(pL,i,a,v,sLe,sRi,h) = (i==fC) ? concat(pL,[rotM(a)*[(sL-sRi)/2,h]+v])
    : generateInnerSide(concat(pL,[
        rotM(a)*[-sL/2+(2*i+2.5)*sL/nC,h]+v, rotM(a)*[-sL/2+(2*i+2.5)*sL/nC,0]+v,
        rotM(a)*[-sL/2+(2*i+1.5)*sL/nC,0]+v, rotM(a)*[-sL/2+(2*i+1.5)*sL/nC,h]+v
        ]),i+1,a,v,sLe,sRi,h);
function rotM(a) = [[cos(a),sin(a)],[-sin(a),cos(a)]];

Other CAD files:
openSCAD/stl/side_triangle.stl
openSCAD/basecone.scad
openSCAD/bottom_print.scad
openSCAD/ABS/bottom_print.scad
openSCAD/ABS/side.scad
openSCAD/ABS/side_print.scad
openSCAD/LED_Case.scad
openSCAD/Magnet-Fixer.scad
openSCAD/complete.scad
openSCAD/front.scad
openSCAD/frontsparse.scad
openSCAD/side_plain.scad
openSCAD/side_print.scad

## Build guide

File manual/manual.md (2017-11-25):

# Stackelichten Build Manual
This short manual explains, how to build your own stackel´nlichten pixel net.

# An LED Trixel

## Required parts
* [Neopixel]([https://learn.adafruit.com/adafruit-neopixel-uberguide/overview) LED (a [WS2812](https://cdn-shop.adafruit.com/datasheets/WS2812.pdf)-type LED)
* 6 [Neodyn magnets](http://www.magnetportal.de/wuerfel/neodym-magnet-wuerfel-n45-4mm-1-3kg/a-64/) of size `4x4x4 mm` (0,10 € from 200 pieces on)
* 1 [Cables for 3 pin](https://www.adafruit.com/products/1663) (1,50 € each) or [the not black cable version](https://www.amazon.com/HKBAYI-50Pair-50sets-Connector-WS2812B/dp/B00NBSH4CA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) (0,24 € each)
* Plywood or plastic (ABS) for the case (depends on whether you want wood cases and have a laser or want ABS cases and have a 3D printer)
* ABS for the LED case
* a trabnslucent (acryl) front plate that spreads the LED light (and a laser cutter), e. g. [Plexiglas satinice](http://www.plexiglas.de/product/plexiglas/de/produkte/plexiglas-satinice/pages/default.aspx) works, too)

## Build the case
First of all produce 3 [side plates](../openSCAD/side.scad) and a [bottom plate](../openSCAD/bottom.scad), either cut them from plywood with a laser or print them in a 3D printer.

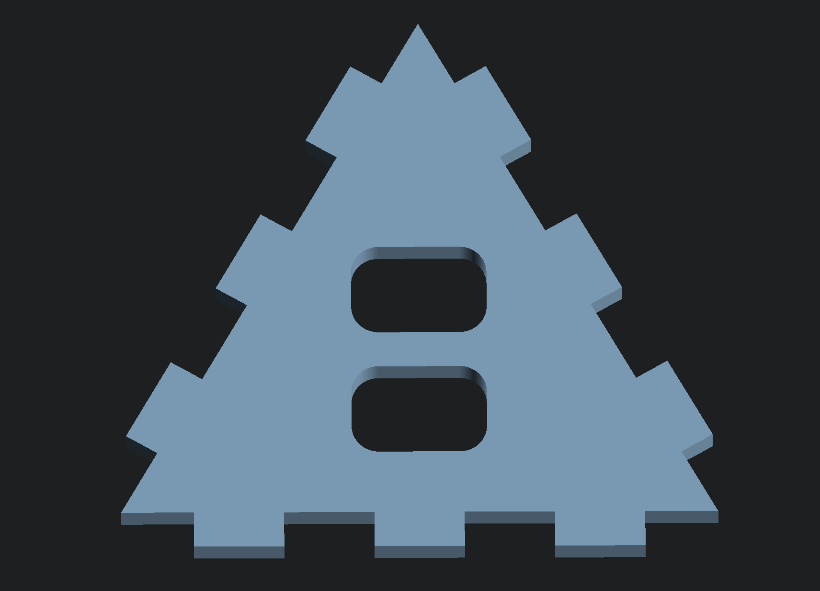
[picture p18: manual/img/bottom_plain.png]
print/cut one the bottom plate

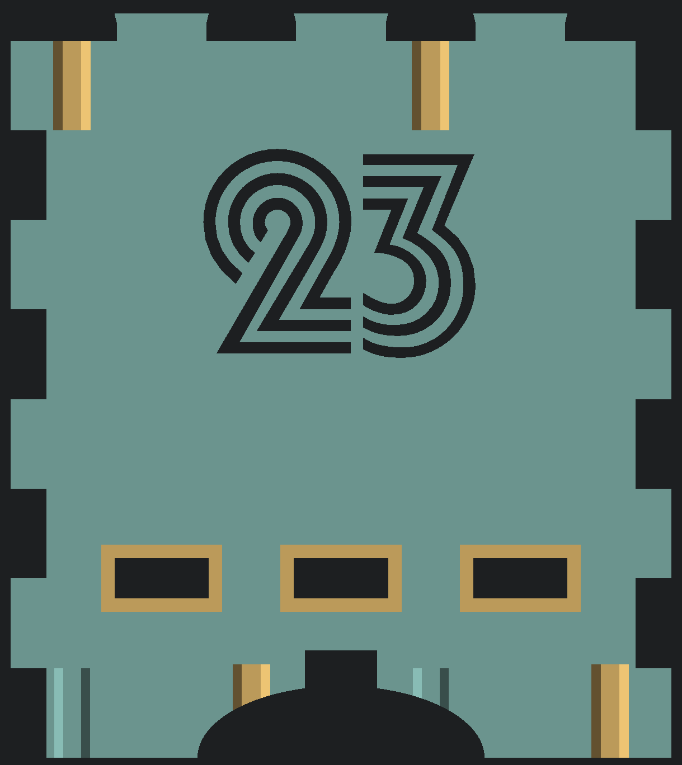
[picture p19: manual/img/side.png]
print/cut three the sides plate


take the magnets and glue them into the two holes of each of the three sides with opposing magnetization. If you look at a side, e.g. the outside of a plate, make sure that the right magnet is a magnetic south pole (i.e. using a compass the north pole points to the right magnet) and the left magnet is a north pole (i.e. the compass south points towards this one). If you fixed that for one side use this to adjust all others.

Glue all three parts together using either wood glue or aceton.

Furthermore cut one front plate from the translucent acryl plate, see [front plate](../openSCAD/front.scad), see this sketch (now you also now where the logo coms from).
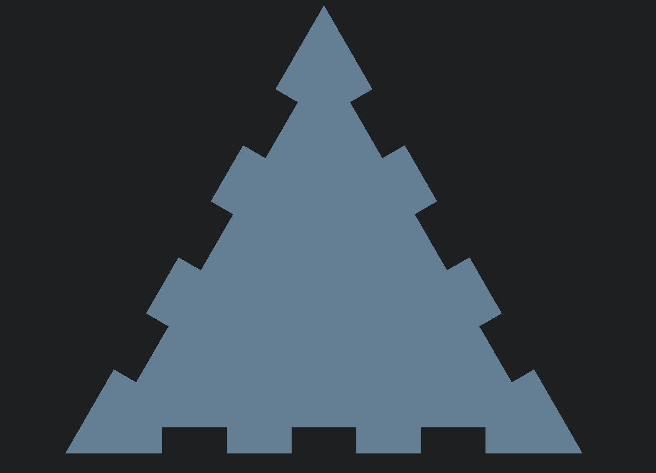
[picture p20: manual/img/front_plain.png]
front plate


## Prepare the LED
First of all print a LED case. You can already check
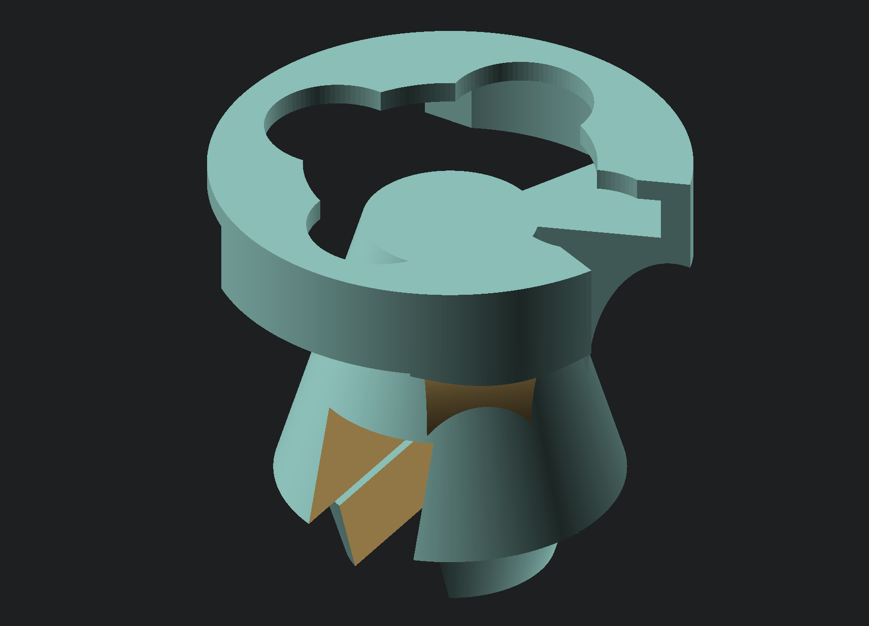
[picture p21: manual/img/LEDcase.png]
LEDcase

[LEDcase-openSCAD](../openSCAD/LED_case.scad).
 Before soldering the LED you can already check, that the case should fit onto the middle bridge of the bottom plate. Note that it might be best to print these upside down, such that you only need a little support for the center code (then pointing downwards).

Wiring your LED should be done something like this, but stop before wiring data out:
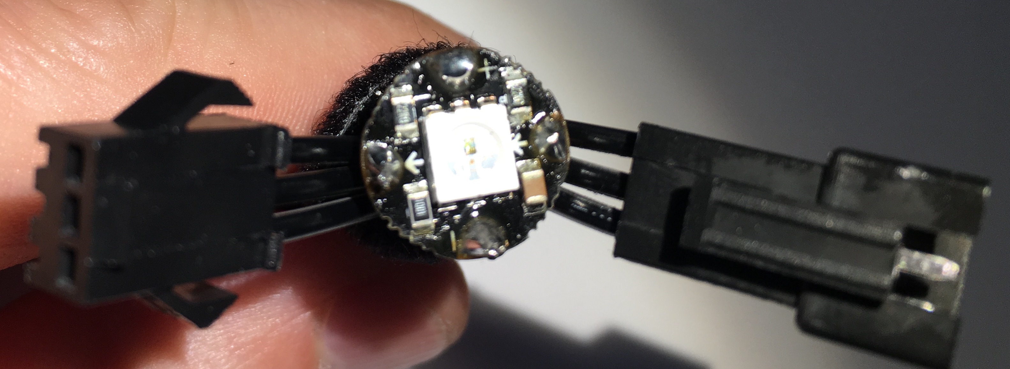
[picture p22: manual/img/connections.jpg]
connections

i.e. if you look onto the plug pointing to the left,
the top pin is plus, the bottom pin is minus and the center pin is connected to data out.
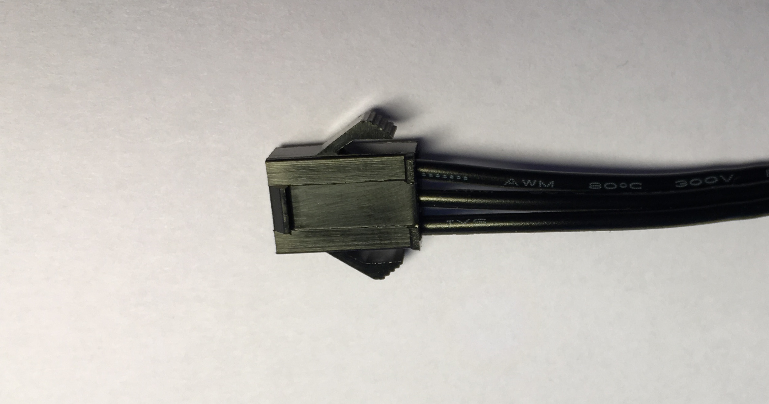
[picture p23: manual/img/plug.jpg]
plug

Similarly for the receptor: if you look upon the receptor (pointing right) the top cable is plus, the bottom cable is minus and its center cable is data in.
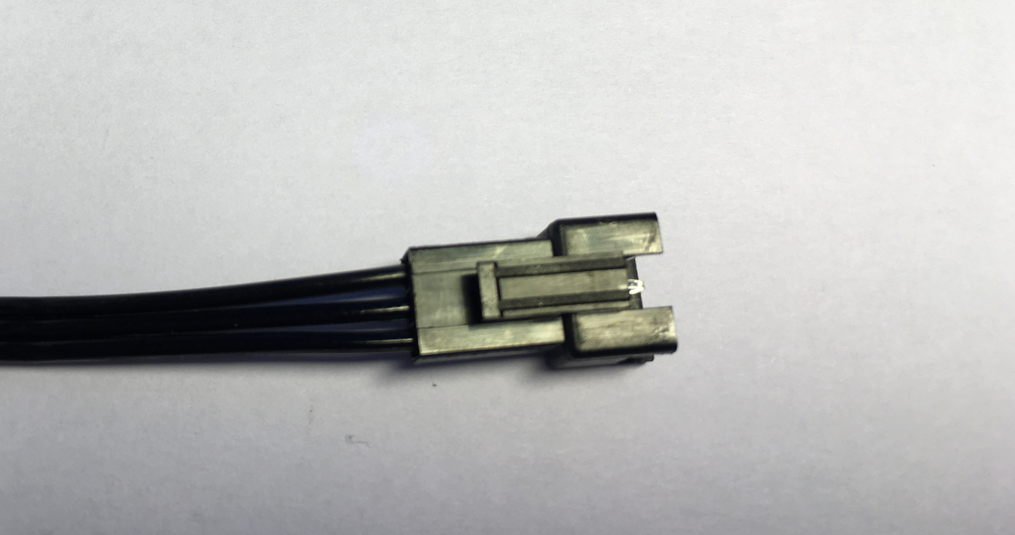
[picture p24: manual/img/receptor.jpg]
receptor


When soldering the cables to the LED as shown in the first image, stop and plug the LED into the LED case,
where the Neopixel shown in the image should fit perfectly. If you then wire the data out, the LED also holds within the case.

Now glue the LEDcase to the bottom after putting it onto the small middle bridge.

You can also glue the case to the bottom plate before glueing the three sides and the bottom together (then the bridge is easier reachable)

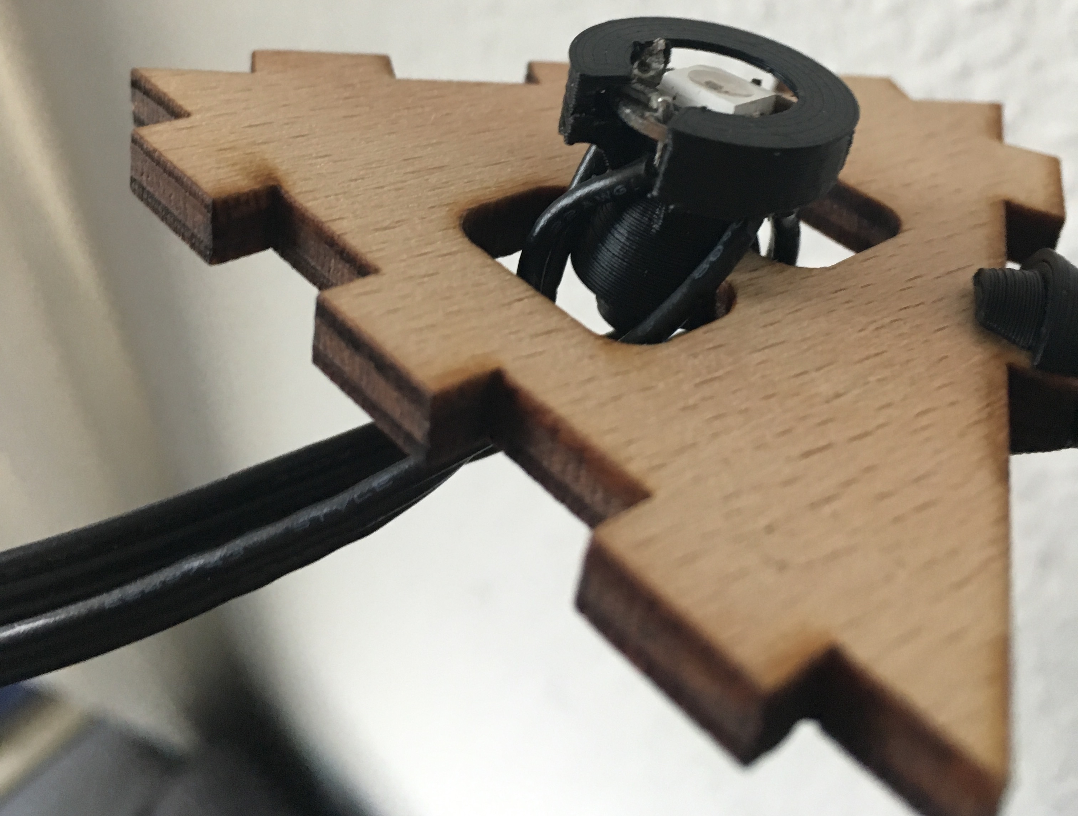
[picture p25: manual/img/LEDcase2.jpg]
LED case on bottom plate


but for me the glueing of the wood/ABS parts was easier without the LED being inside.

The only thing left for a case is now to fix the front plate. In my tests the ABS just clamps the acryl, while for the wood cases it's a little tricky to fix the front plate.

# The controller

The Python Code in `src/` is based on the MVC model and consists of

* `Pixel.py` containing the class of a single pixel
* `Graph.py` contains a class modelling a set of pixel as vertices in a graph and their edges with length and directions beweteen pixel mid points to model a neighborhood.

* `algorithm.py` a class inheriting the graph as a decorator model to perform algorithms on the graph. The algorithm itself impements both an observer as well as an observable in oder to exchange information between algorithm instances, i.e. between the game `AlgSnake` and a `AlgDigit` to display the score. The algorithms range from metaAlgorithms that combine algorithms to specific small tasks.
* `control.py` a controller class and its children reacting on keyboard inputs and modifying the model, an `Algorithm` using the Observer model. This hence controls exactely one algorithm (that may consist of subalgorithms)
 * A `SimpleControl` just reacting on `Ctrl+C` and turns of the LEDs then (ending the algorithm)
 * A `DirectionControl` taking erfvcd as the 6 directions one may walk on the graph (onto trixel having an adjacent line and not just a triangle edge) as well as walinkt by `kl` turnig left (k) or right(l) by 60 degrees.
* `vizualization.py` the interface `StackenLichtenVisualization` to different views, most prominently encapsulating the OPC library (`opc.py`) that pushed to fadecandy boards and a MatPlotLib and a PyTurtle implementation for programmming the algorithms on a computer, when the Stackenlichten is not available
 * `fadeCandySLV` - pushing the graph to the opc library
 * `PyMatplotSLV` - using the MatplotLib to draw the graph
 * `PyTurtleSLV` - using Python Turtle to display the trixel and algorithms (a little slow).
They all posess a render function that takes a graph to render it onto the given physical context they represent.

In order to run and display an algorithm, write the algorithm itself as a subclass of `Algorithm`, encapsulate this into a `mainAlgorithm`, that takes care of displaying the state of the graph qhile an (an inner algorithm is ) running.
This mainAlgorithm is then passed to the control, which takes care of actually running the algorithm using its `step()` and `isFinished()` functions and passes user actions to the algorithm or all other classdes subscribed as observers to the `Control`.

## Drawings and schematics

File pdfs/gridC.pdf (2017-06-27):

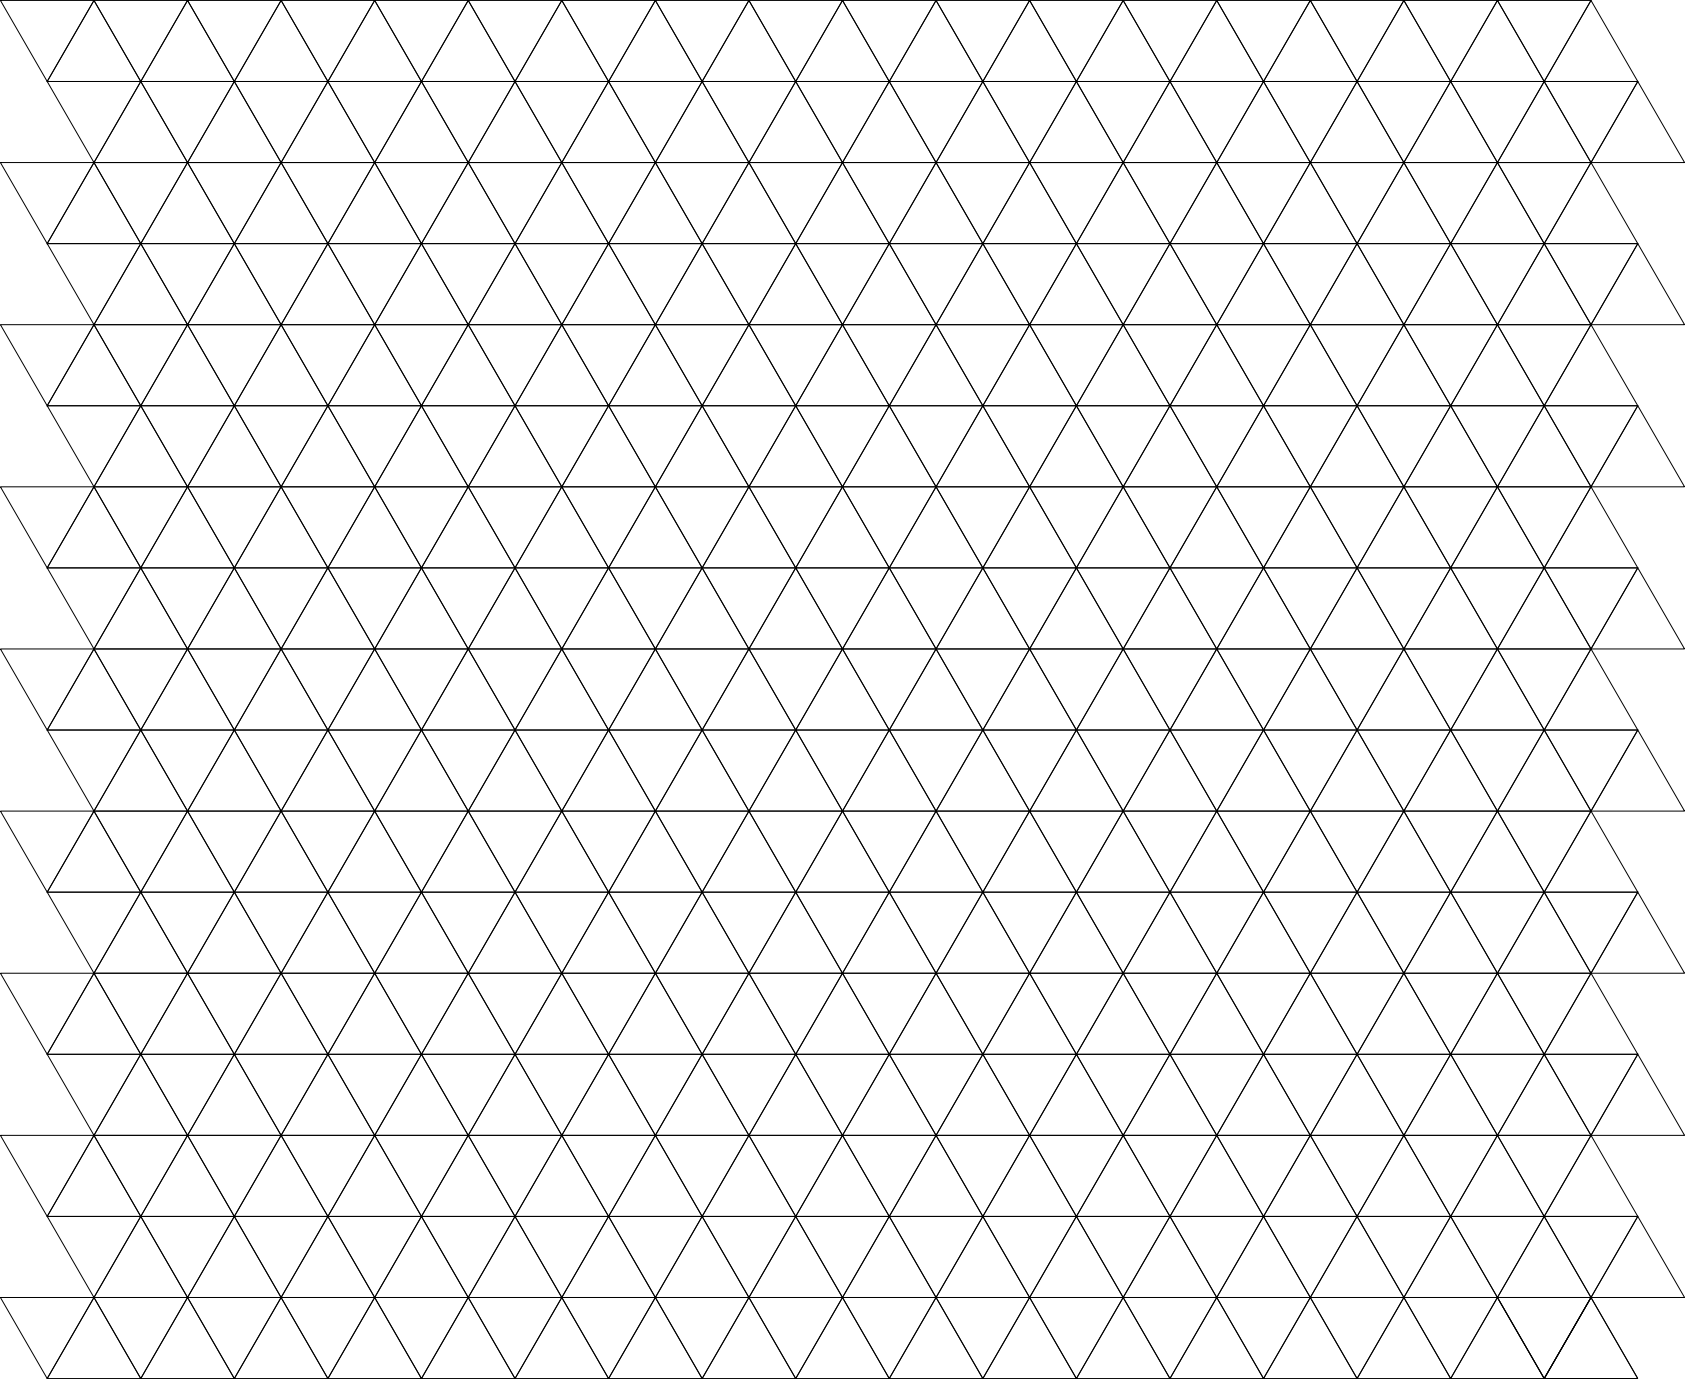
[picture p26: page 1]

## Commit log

2016-12-31 updates bottom pate form and magnet placement to be more symmetric.
2017-01-02 found a cheaper source for magnets, added comments on the power supply. Second color theme for the logo.
2017-02-18 und das png
2017-02-19 eine erste openSCAD-Version.
    [front.scad]
2017-02-19 erste Version der Seitenfläche.
    [complete.scad, side.scad]
2017-02-20 updates side measurements in sketches after checking with the 3D model, adds bottom plate, holes in side plates and a cable channel to side plates.
    [bottom.scad, complete.scad, side.scad]
2017-03-14 new bottom plate design to be able to fir for both plug&receptable.
    [bottom.scad, complete.scad]
2017-03-17 first difference() then linear_extrude makes everything(!) nicer!
    [bottom.scad, complete.scad, side.scad]
2017-03-21 side: flach & gelegt
    [side.scad]
2017-03-22 changes rules of creation: first 2D then 3D.
    [basecone.scad, bottom.scad]
2017-03-24 unify both cable opening in the bottom plate, because the cables both fit the smaller hole.
    [bottom.scad, side.scad]
2017-03-25 updates base cone size.
    [basecone.scad]
2017-04-04 adds a connection fix.
    [basecone.scad, complete.scad, stack.scad]
2017-04-14 adds a first image of the cable usage for data in/out and +-.
2017-04-15 switch LEDs off on Strg+C and adds a simple RunningLight.
2017-04-16 a final baseCone; and the idea for an Advanced Cone, such that one data cable is soldered after moving the LED into the cone; not sure whether that’s printable….but the idea should work if its printa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
    [AndvancedCone.scad, baseconeFINAL.scad]
2017-04-18 further work on the idea of an advanced cone.
    [AndvancedCone.scad]
2017-04-30 add own support material.
    [AndvancedCone.scad, bottom.scad, front.scad]
2017-05-13 finishes the openSCAD models and an export stl.
    [AdvancedCone30-4Stk.stl, LED_Case.scad, base_cut_plate.stl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]
2017-05-13 still some minor tweaks.
    [AdvancedCone30-4Stk.stl, LED_Case.scad, LED_Case.stl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]
2017-07-10 adds an idea for ABS-Printed parts.
    This includes a new techique to fix the magnets (.6mm at the closed front and a glueable Magnet fixer inside).
    The LED-Case still has to be put onto the bottom plate as before. Though the case now looks fancier from outside.
    And hopefully the front plate will fit better and hold itself (first tests support this).
    [Magnet-Fixer.scad, bottom_print.scad, side_print.scad]
2017-07-15 removes a lot of temporary data and images from the repository.
    [LED_Case.scad, Magnet-Fixer.scad, base_cut_plate.stl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]
2017-07-15 adds a second variant of a abs side.
    [side_print2.scad]
2017-08-06 changes message passing to an observer model, which still passes down hierarchical algorithms, though.
    [Magnet-Fixer.scad, bottom_print.scad]
2017-09-02 rewrite Snake.py to accept graph, display mode and framerate as command line arguments.
2017-09-04 adds a PyGame based viualization, that lacks a small stalling and focus problem.
2017-10-02 adds a graph19 (100 pixel!) and its special boundary version, where negative edges indicate that the neighbor is stepping over one (i.e. both are upright or downwards pointing) which opccurs at bound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
    [LED_Case.scad, Magnet-Fixer.scad, bottom_print.scad]
2017-10-18 adds short demos for the MetaNooK.
    [bottom_print.scad, complete.scad, front.scad]
2017-11-25 updated the manual and added orientation of the magnets.
    [bottom_print.scad]
2017-11-25 updats manual to a new side image.
    [Title.scad, side.scad, side_print2.scad]
2018-05-07 Rearrange scad files (add Finger Tolerance proposed by @int2001) and add exemplary STLs
    [Magnet-Fixer.scad, Title.scad, bottom_plain.scad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]
2018-08-23 Introduces a few optimizationd and a script for mass stl export.
    [LED_Case.scad, Magnet-Fixer.scad, bottom_print.scad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]
